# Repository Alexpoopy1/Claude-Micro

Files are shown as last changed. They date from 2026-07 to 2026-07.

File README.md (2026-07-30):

# Claude Micro

A 13-key agent macropad on clear MX switches: six frosted status keys, seven
command keys, a rotary reasoning dial, a planar joystick, a five-pad capacitive touch
strip and a 19-LED RGB chain. Fully printable, fully routed, fully checked.

Design study of the [Work Louder × OpenAI Codex Micro][codex] — same feature
set (13 switches, 1 encoder, 1 planar joystick, 1 touch sensor, 6 agent keys),
rebuilt from scratch as open hardware with the Claude mark on the front.

[codex]: https://openai.com/supply/co-lab/work-louder/

```
make            # build everything, then verify it
open build/claude-micro.html
```

Deploying to Vercel serves the same file: `vercel.json` runs the STL, PCB and
HTML build steps and publishes `build/` as the site, with `/` rewritten to
`claude-micro.html`. No framework, no Node build — just the Python tooling
above, so the deployed page is always generated fresh from
`config/device.json` rather than a stale checked-in copy.

## What you get

| Output | Where | What it is |
| --- | --- | --- |
| **Interactive viewer** | `build/claude-micro.html` | One self-contained file: WebGL model with an exploded-view slider, PCB layer viewer, schematic, BOM, print guide, firmware reference and the full check report. No network, no CDN. |
| **Printable parts** | `build/stl/*.stl` | 9 parts, 22 pieces, ~88 g of filament. Every one proven watertight before it is written. |
| **PCB** | `build/pcb/claude-micro.kicad_pcb` | Open in KiCad 7/8. Placed, routed, poured, zoned. Also `.kicad_sch`, `.kicad_pro`, `.net`. |
| **EasyEDA schematic** | `build/pcb/claude-micro-easyeda.json` | `make easyeda`. Opens in EasyEDA (File → Open → EasyEDA) and imports into EasyEDA Pro via File → Import → EasyEDA Standard — for publishing to OSHWLab or ordering through JLCPCB. |
| **Fabrication** | `build/pcb/gerbers/` | RS-274X gerbers for all nine layers plus separate plated and non-plated Excellon drill files. Upload as-is. |
| **Assembly** | `build/pcb/bom.csv`, `positions.csv` | 18 BOM lines, 89 components, pick-and-place positions. |
| **Firmware** | `firmware/qmk/claude_micro/` | Drop-in QMK keyboard folder. |
| **Reports** | `build/pcb/drc_report.json`, `build/stl_report.json` | Machine-readable results of every check. |

## Hardware

|  |  |
| --- | --- |
| Keys | 13 × clear-housing MX switches, 5-pin PCB mount, on a 19.05 mm grid — 6 agent, 7 command |
| Dial | EC11E rotary encoder with push, on a 26 mm knurled knob |
| Joystick | 20 mm 2-axis analog thumbstick into ADC0/ADC1, click on its own pin |
| Touch | 5-pad strip read by RC charge time — no touch controller |
| RGB | 19 × SK6812 (13 per-key + 6 underglow), 5 V through a 74LVC1G17 buffer |
| MCU | RP2040 module, Raspberry Pi Pico form factor (USB-C variant recommended) |
| Board | 159 × 102 mm, 2 layer, 1.6 mm, 0.2 mm rules |
| Case | 165 × 108 × 19.5 mm printed two-piece, 6° tilt feet |

### Agent keys

The six frosted keys mirror six host threads. The host pushes state over raw
HID and the board renders it:

| State | Colour | |
| --- | --- | --- |
| idle | white | nothing running |
| thinking | blue, breathing | model is reasoning |
| running | light blue, breathing | tools are executing |
| waiting | amber | needs your input |
| done | green | finished cleanly |
| error | red | failed |

If the host goes quiet for 30 s every key falls back to idle, so a crashed
bridge never leaves stale status on the desk.

### The dial

Turning it walks reasoning effort — low → medium → high → max. Pressing it is
an ordinary matrix key (row 3, col 1), so it can be remapped like any other.

## How it is built

Everything derives from **`config/device.json`**. Change the key pitch there
and the STLs, the board, the firmware descriptors and the viewer all move
together; the test suite fails if any of them disagree.

```
config/device.json      one source of truth
        │
tools/  device.py       loader + derived layout (LED chain, matrix nodes, pads)
        mesh.py         watertight mesh kernel (no CSG, no dependencies)
        parts.py        every physical part, printable and purchased
        circuit.py      schematic as data: components, footprints, nets
        router.py       grid maze router + copper pour generator
        build_pcb.py    place → route → pour → check
        outputs.py      KiCad, gerbers, Excellon, BOM, board.json
        checks.py       ERC + DRC + mechanical fit
        schematic.py    SVG schematic
        build_easyeda.py   schematic → EasyEDA Standard source
        build_stl.py    printable parts → binary STL
        build_html.py   the single-file viewer
        build_firmware.py  QMK descriptors
tests/  test_all.py     36 checks across geometry, layout, circuit and board
```

No third-party packages. Python 3.11 standard library only.

### The mesh kernel

There is no CSG. Every solid is built from operations that are watertight by
construction — polygon extrusion, lofting, and lathing — and the awkward case
(capping an outline riddled with holes) is handled by a trapezoidal scanline
decomposition that re-subdivides the side walls so caps and walls share exactly
the same vertices. `Mesh.validate()` then *proves* each part is a closed,
consistently oriented 2-manifold with positive volume, and `build_stl.py`
refuses to write a file that fails.

### The router

The board is rasterised onto a 0.2 mm grid where every piece of copper is
stamped along with its clearance halo, so "may net N occupy this cell?" is one
array lookup. Nets are then routed shortest-first with A* over that grid, with
a cost for changing layer and a separate keepout map that stops a via being
drilled too close to another hole. Leftover free space becomes the ground pour,
emitted as scanline runs. Any GND pad the pour cannot reach gets found by a
flood fill and routed in with a track — the same flood fill the DRC uses, so
the fixer and the checker cannot drift apart.

## Verification

`make test` runs 36 checks:

* **Geometry** — kernel invariants, analytic volume checks, a fuzz pass over
  random hole patterns, and every printable part proven watertight, manifold,
  correctly oriented, printer-sized and thick enough to print.
* **Layout** — key pitch, top-surface collisions, bezel window clearances, a
  monotonic Z stack, and that the encoder shaft does not bottom out in the knob.
* **Circuit** — ERC, one switch and one diode per matrix node, unique matrix
  addresses, an unbroken LED chain, no double-booked GPIO, the LED rail fused
  and level-shifted, the touch strip fully wired.
* **Board** — every connection routed, ≥ 0.2 mm copper clearance verified on a
  fresh raster of the finished geometry, annular rings, hole-to-hole spacing,
  all copper inside the profile, the ground pour reaching every GND pad, no
  courtyard overlaps, and nothing under the MCU module taller than its standoff.
* **Outputs** — balanced s-expressions in the KiCad files, well-formed gerbers
  and Excellon, drill counts matching the board, the BOM covering every
  component, the viewer free of external references, and the firmware agreeing
  with the config on pins, LED count, layers and layout size.
* **EasyEDA** — every shape string matching EasyEDA's documented field order,
  no duplicate ids, and the connectivity rebuilt out of the exported file the
  way EasyEDA reads it — pin dot → wire → net label — coming back identical to
  the source netlist, all 265 pads and 68 nets.

Current status: **0 DRC errors, 0 warnings, 141/141 connections routed, 9/9
meshes watertight.**

## Building one

1. **Print** at 0.2 mm, 3 walls, 25% infill. No supports on any part. Print the
   six agent keycaps in natural or clear filament — the roof is 1.0 mm so the
   status colour reads through. All 13 caps take a standard MX cross stem, so
   bought keycaps drop straight in if you would rather not print them.
2. **Order the PCB** — upload `build/pcb/gerbers/` as a zip. Nothing exotic:
   2 layer, 1.6 mm, 0.2 mm track and clearance.
3. **Populate** — bottom side first (diodes, 0603s, the SOT-23-5, then the
   RP2040 module on a 2.54 mm header), then the top: the 19 SK6812s, then the
   13 MX switches, the EC11 and the thumbstick. Seat every switch fully — the
   two locating posts must bottom out before you solder, or the plate will not
   sit flat.
4. **Flash** — `qmk compile -kb claude_micro -km default`, hold BOOTSEL, copy
   the UF2 across.
5. **Assemble** — six M2 heat-set inserts in the bezel, drop the diffuser into
   the touch window, six M2 × 6 mm screws from underneath.

Full step-by-step with per-part orientation is in the viewer's
**Print & assemble** tab.

## Licence

Hardware and firmware are open. The Claude mark is Anthropic's; it is used here
on a personal build, not a product for sale.

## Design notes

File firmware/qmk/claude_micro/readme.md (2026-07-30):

# Claude Micro (QMK)

Drop this folder into `qmk_firmware/keyboards/` and build:

    qmk compile -kb claude_micro -km default

Flash by holding BOOTSEL on the RP2040 module while plugging in USB, then
copying the resulting `.uf2` onto the `RPI-RP2` drive that appears.

| File | What it does |
| --- | --- |
| `keyboard.json` | Matrix pins, encoder, RGB layout, USB descriptors — generated from `config/device.json` |
| `config.h` | Joystick, touch-strip and RGB tuning |
| `matrix.c` | 4x4 COL2ROW scan plus the thumbstick click on its own pin |
| `claude_micro.c` | Agent status LEDs, RC touch strip, joystick-to-skill mapping |
| `keymaps/default/keymap.c` | Six layers, encoder map, host-bridge keycodes |

Everything here is regenerated by `make firmware`, and `make test` fails if the
firmware and `config/device.json` ever disagree about pins, LED count or layers.

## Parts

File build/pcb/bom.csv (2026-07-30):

Qty | Value | Footprint | MPN / Notes | References | Description | Group
22 | 100nF | C_0603 | - | C1 C10 C11 C12 C13 C14 C15 C16 C17 C18 C19 C2 C20 C24 C25 C3 C4 C5 C6 C7 C8 C9 | Encoder B debounce | input
14 | 1N4148W | D_SOD123 | 1N4148W SOD-123 | D1 D10 D11 D12 D13 D14 D2 D3 D4 D5 D6 D7 D8 D9 | Matrix diode for ENC_SW | matrix
13 | MX clear | MX_PCB | MX-compatible, clear housing, 5-pin | SW1 SW10 SW11 SW12 SW13 SW2 SW3 SW4 SW5 SW6 SW7 SW8 SW9 | Key K7 | matrix
13 | SK6812MINI-E | SK6812MINI | SK6812MINI-E | LED1 LED10 LED11 LED12 LED13 LED2 LED3 LED4 LED5 LED6 LED7 LED8 LED9 | Per-key status RGB | rgb
6 | SK6812-3535 | SK6812_3535 | SK6812-3535 | LED14 LED15 LED16 LED17 LED18 LED19 | Underglow RGB | rgb
5 | 1M | R_0603 | - | R5 R6 R7 R8 R9 | RC touch drive resistor, pad 4 | touch
2 | 10uF | C_0805 | - | C22 C23 | 3V3 bulk | power
2 | 10k | R_0603 | - | R1 R2 | Encoder B pull-up | input
2 | 1k | R_0603 | - | R3 R4 | Joystick Y RC filter | input
2 | 10nF | C_0603 | - | C26 C27 | Joystick Y filter cap | input
1 | RP2040 Pico-form-factor module | RP2040_Module_Pico | YD-RP2040 / RP2040-Plus / Raspberry Pi Pico | MOD1 | RP2040 + 2-16 MB flash + USB + 3V3 regulator | mcu
1 | 470R | R_0603 | - | R10 | Data line series damping | rgb
1 | 74LVC1G17 | SOT-23-5 | SN74LVC1G17DBVR | U2 | Schmitt buffer, 3V3 -> 5V for SK6812 data | power
1 | 1.1A PPTC | F_1206 | MF-MSMF110 | F1 | Resettable fuse on the 5 V rail | power
1 | 470uF 10V | C_1210_BULK | Low-ESR bulk | C21 | LED rail bulk capacitance | power
1 | EC11E + switch | EC11E | EC11E15244Ax (9 mm shaft) | ENC1 | Reasoning-effort dial | input
1 | 2-axis analog thumbstick | Joystick_20mm | 20 mm planar thumbstick, 10k pots | JS1 | Skill launcher | input
1 | Reset | SW_Push_6mm | - | SW_RST | Pulls RUN low | mcu

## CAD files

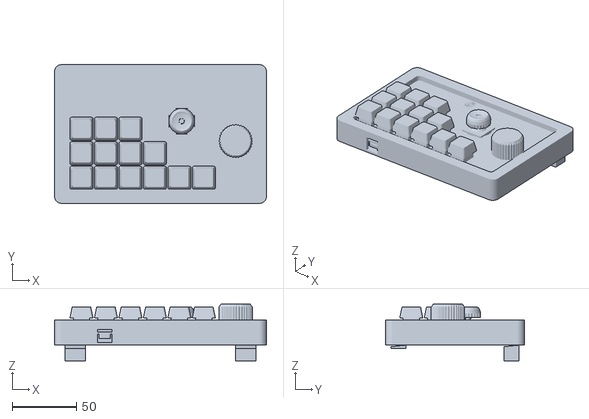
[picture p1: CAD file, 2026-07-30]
build/stl/assembly.stl
165.0 x 108.0 x 44.2

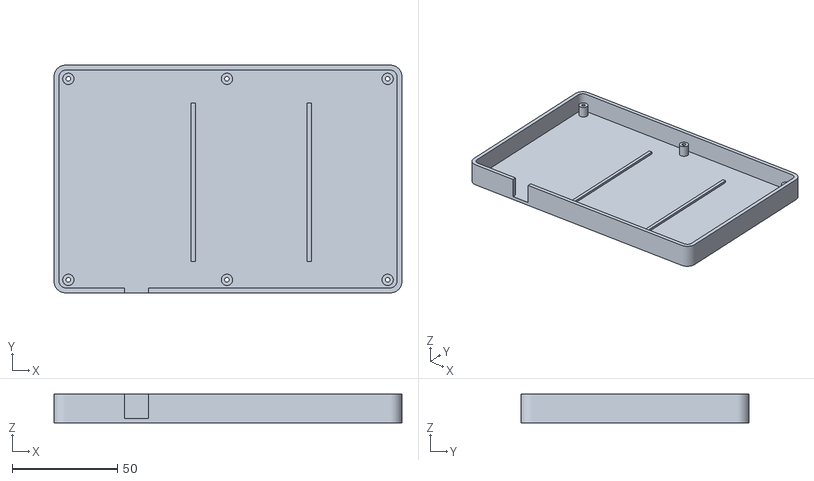
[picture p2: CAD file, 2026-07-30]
build/stl/case_bottom.stl
165.0 x 108.0 x 13.6

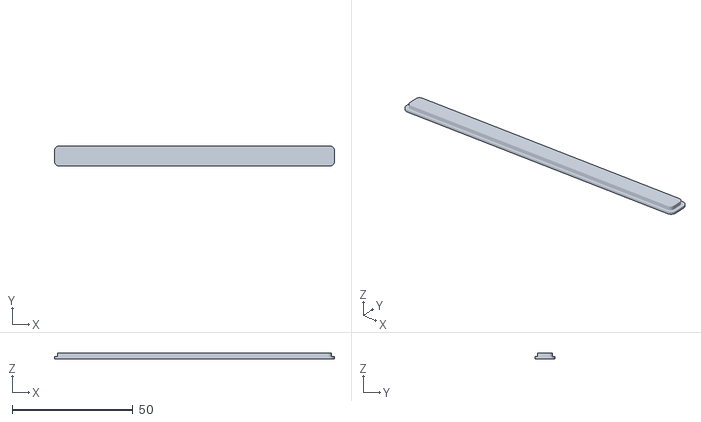
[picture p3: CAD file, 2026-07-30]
build/stl/diffuser.stl
115.8 x 8.40 x 2.30

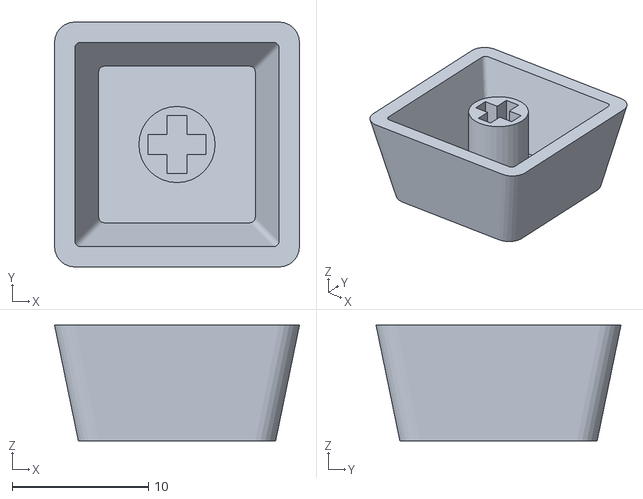
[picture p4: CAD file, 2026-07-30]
build/stl/keycap_agent.stl
18.0 x 18.0 x 8.50

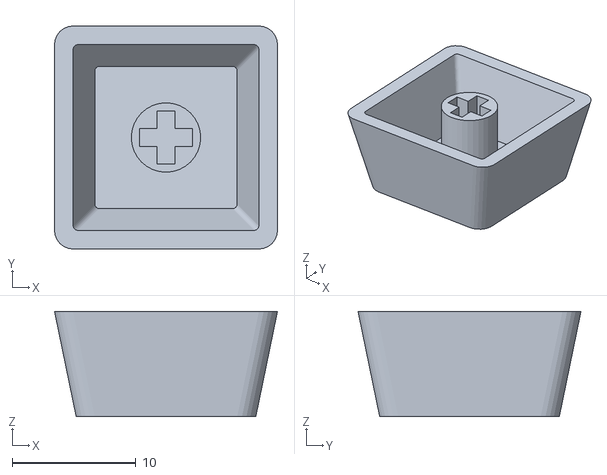
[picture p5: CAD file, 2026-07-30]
build/stl/keycap_command.stl
18.0 x 18.0 x 8.50

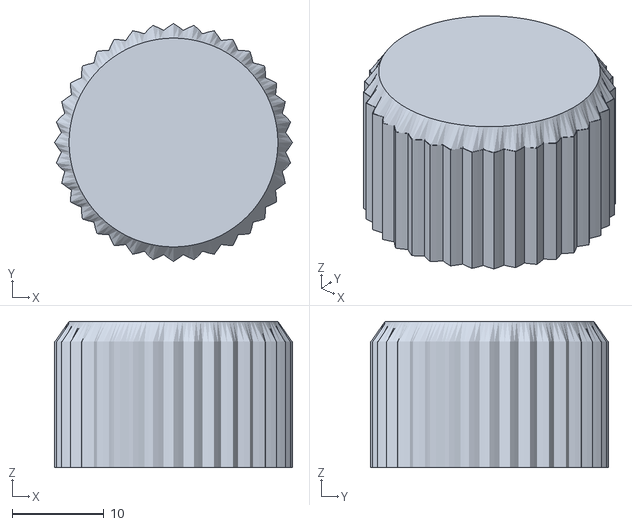
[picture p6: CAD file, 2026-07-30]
build/stl/knob.stl
26.0 x 26.0 x 16.0

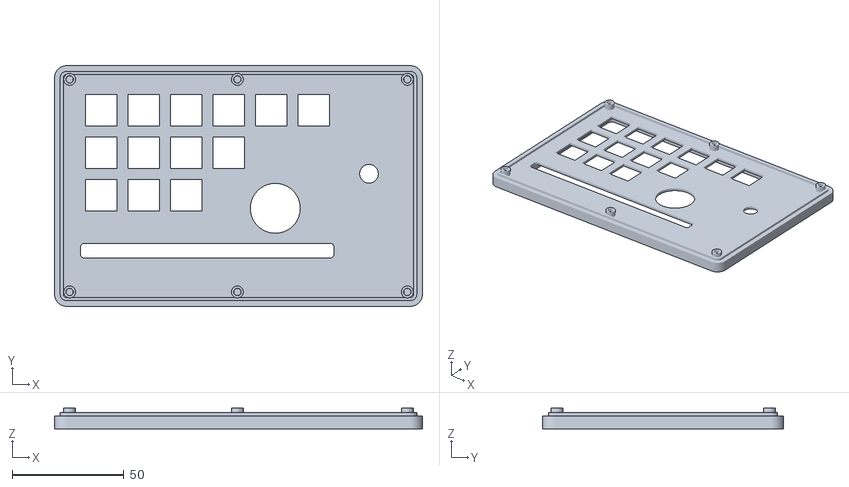
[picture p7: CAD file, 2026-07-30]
build/stl/case_top.stl
165.0 x 108.0 x 9.35

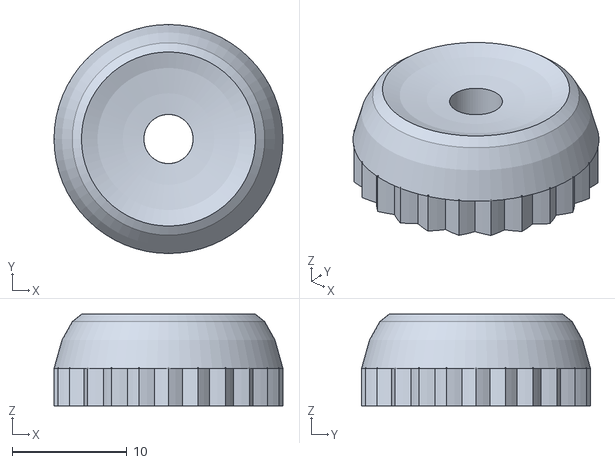
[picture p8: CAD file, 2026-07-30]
build/stl/joystick_cap.stl
20.0 x 20.0 x 8.00

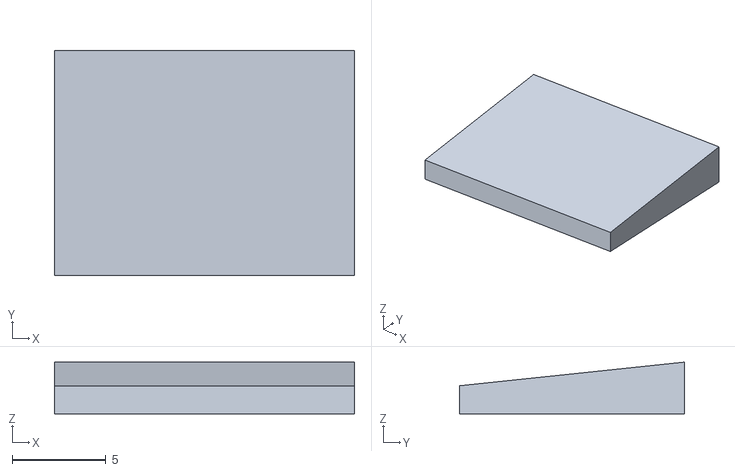
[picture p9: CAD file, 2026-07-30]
build/stl/foot_front.stl
16.0 x 12.0 x 2.76

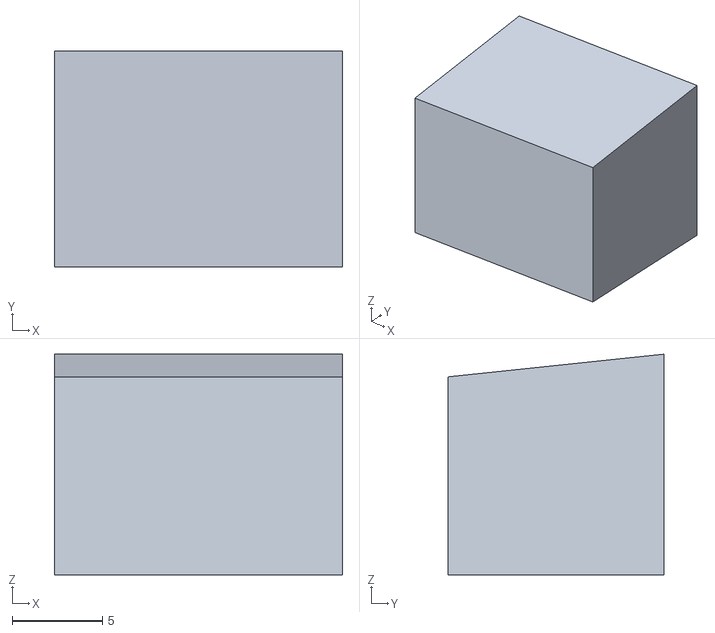
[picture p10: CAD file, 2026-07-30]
build/stl/foot_rear.stl
16.0 x 12.0 x 12.3

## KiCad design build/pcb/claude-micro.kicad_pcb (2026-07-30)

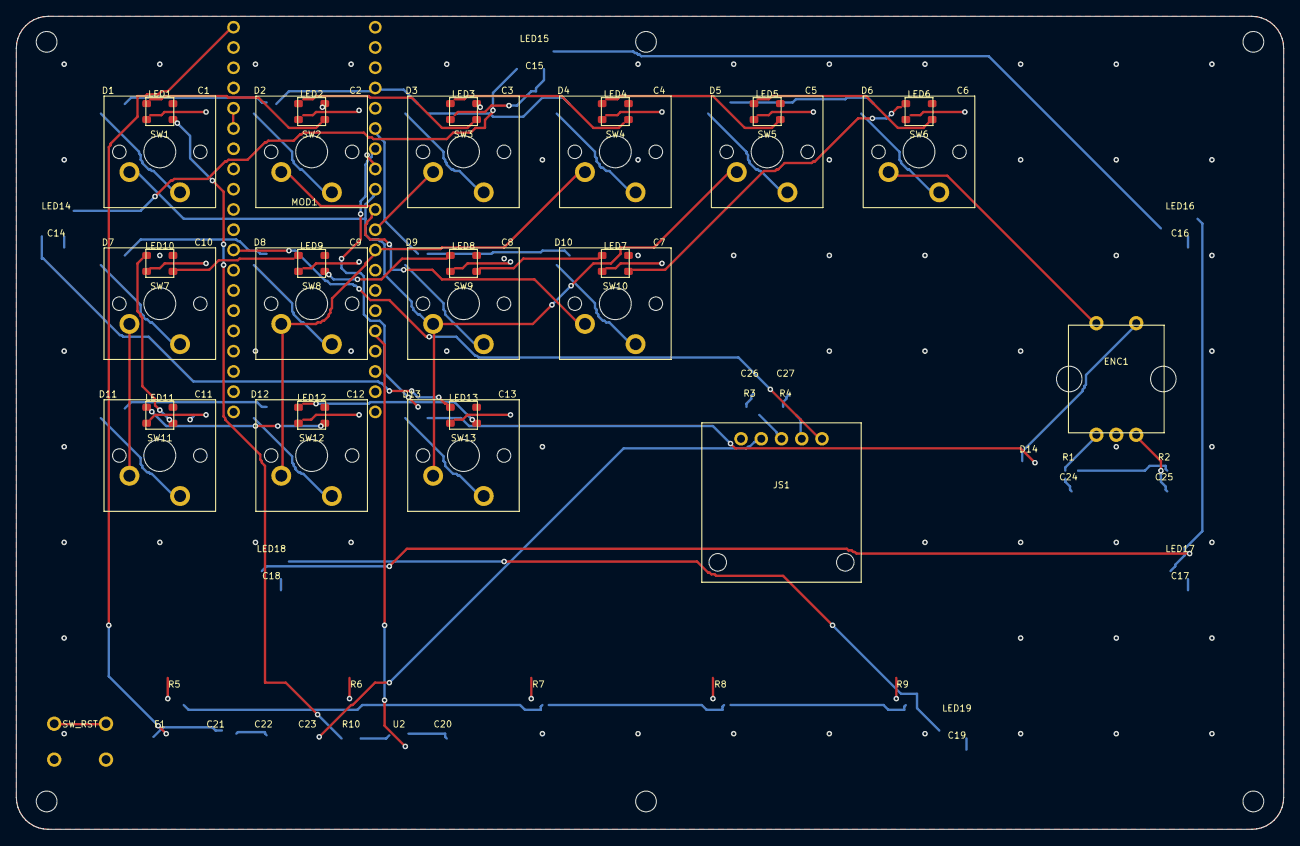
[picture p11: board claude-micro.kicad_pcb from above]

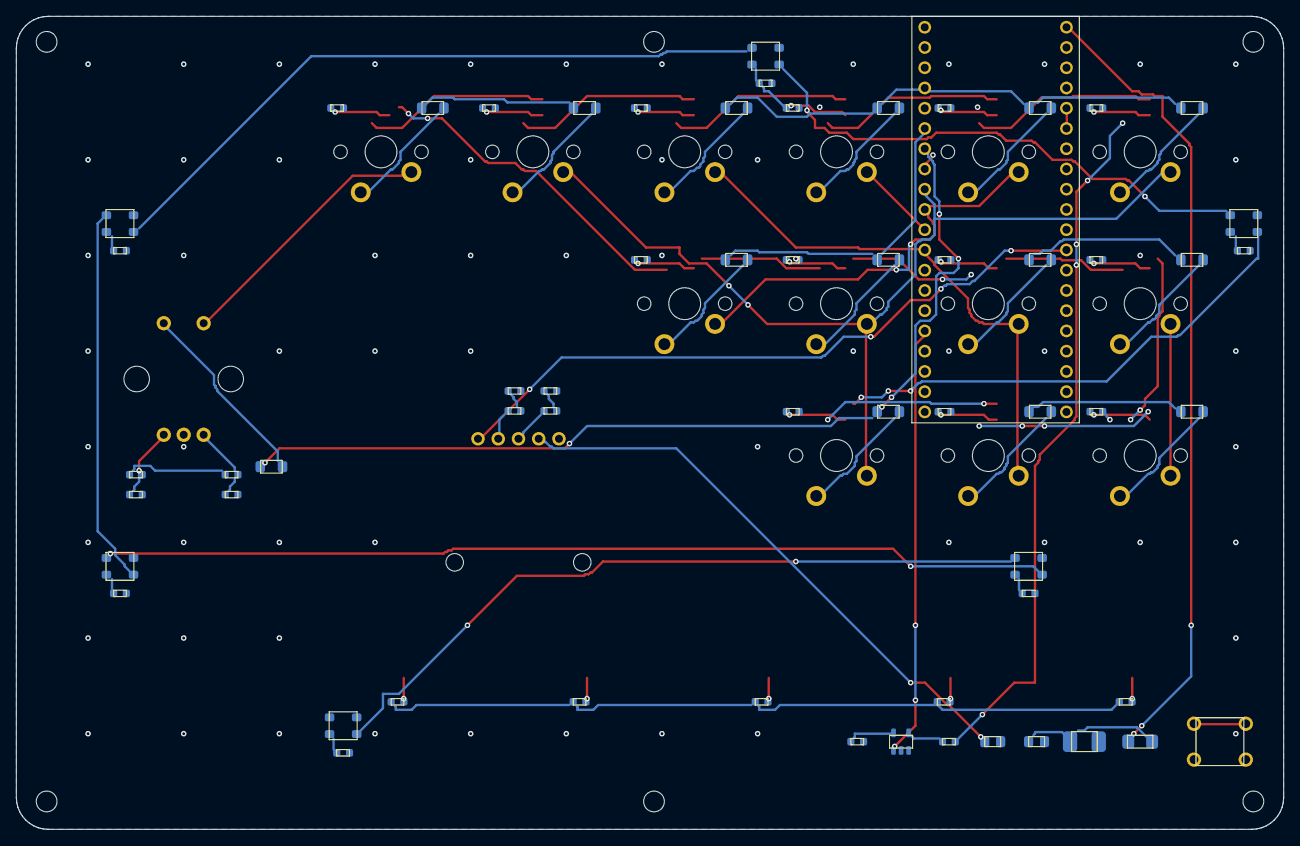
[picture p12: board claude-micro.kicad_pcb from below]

Board: 2 copper layers, 159.0 x 102.0 mm, 89 parts (61 on the bottom side), 61 nets.

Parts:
C1, C2, C3, C4, C5, C6, C7, C8, C9, C10, C11, C12, C13, C14, C15, C16, C17, C18, C19, C20, C24, C25: 100nF; C_0603
C21: 470uF 10V; C_1210_BULK
C22, C23: 10uF; C_0805
C26, C27: 10nF; C_0603
D1, D2, D3, D4, D5, D6, D7, D8, D9, D10, D11, D12, D13, D14: 1N4148W; D_SOD123
ENC1: EC11E + switch; EC11E
F1: 1.1A PPTC; F_1206
JS1: 2-axis analog thumbstick; Joystick_20mm
LED1, LED2, LED3, LED4, LED5, LED6, LED7, LED8, LED9, LED10, LED11, LED12, LED13: SK6812MINI-E; SK6812MINI
LED14, LED15, LED16, LED17, LED18, LED19: SK6812-3535; SK6812_3535
MOD1: RP2040 Pico-form-factor module; RP2040_Module_Pico
R1, R2: 10k; R_0603
R3, R4: 1k; R_0603
R5, R6, R7, R8, R9: 1M; R_0603
R10: 470R; R_0603
SW1, SW2, SW3, SW4, SW5, SW6, SW7, SW8, SW9, SW10, SW11, SW12, SW13: MX clear; MX_PCB
SW_RST: Reset; SW_Push_6mm
U2: 74LVC1G17; SOT-23-5

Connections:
+3V3: C23.1, JS1.2, MOD1.35, MOD1.36, R1.1, R2.1
+5V: C1.1, C2.1, C3.1, C4.1, C5.1, C6.1, C7.1, C8.1, C9.1, C10.1, C11.1, C12.1, C13.1, C14.1, C15.1, C16.1, C17.1, C18.1, C19.1, C20.1, C21.1, C22.1, F1.2, LED1.1, LED2.1, LED3.1, LED4.1, LED5.1, LED6.1, LED7.1, LED8.1, LED9.1, LED10.1, LED11.1, LED12.1, LED13.1, LED14.1, LED15.1, LED16.1, LED17.1, LED18.1, LED19.1, U2.5
COL0: MOD1.9, SW1.1, SW5.1, SW9.1, SW13.1
COL1: ENC1.S1, MOD1.10, SW2.1, SW6.1, SW10.1
COL2: MOD1.11, SW3.1, SW7.1, SW11.1
COL3: MOD1.12, SW4.1, SW8.1, SW12.1
ENC_A: C24.1, ENC1.A, MOD1.14, R1.2
ENC_B: C25.1, ENC1.B, MOD1.15, R2.2
GND: C1.2, C2.2, C3.2, C4.2, C5.2, C6.2, C7.2, C8.2, C9.2, C10.2, C11.2, C12.2, C13.2, C14.2, C15.2, C16.2, C17.2, C18.2, C19.2, C20.2, C21.2, C22.2, C23.2, C24.2, C25.2, C26.2, C27.2, ENC1.C, JS1.1, LED1.3, LED2.3, LED3.3, LED4.3, LED5.3, LED6.3, LED7.3, LED8.3, LED9.3, LED10.3, LED11.3, LED12.3, LED13.3, LED14.3, LED15.3, LED16.3, LED17.3, LED18.3, LED19.3, MOD1.3, MOD1.8, MOD1.13, MOD1.18, MOD1.23, MOD1.28, MOD1.33, MOD1.38, SW_RST.3, SW_RST.4, U2.2
JOY_SW: JS1.5, MOD1.29
JOY_X: C26.1, MOD1.31, R3.2
JOY_XR: JS1.3, R3.1
JOY_Y: C27.1, MOD1.32, R4.2
JOY_YR: JS1.4, R4.1
K_A1: D1.2, SW1.2
K_A2: D2.2, SW2.2
K_A3: D3.2, SW3.2
K_A4: D4.2, SW4.2
K_A5: D5.2, SW5.2
K_A6: D6.2, SW6.2
K_ENC_SW: D14.2, ENC1.S2
K_K1: D7.2, SW7.2
K_K2: D8.2, SW8.2
K_K3: D9.2, SW9.2
K_K4: D10.2, SW10.2
K_K5: D11.2, SW11.2
K_K6: D12.2, SW12.2
K_K7: D13.2, SW13.2
LED_D1: LED1.2, LED2.4
LED_D2: LED2.2, LED3.4
LED_D3: LED3.2, LED4.4
LED_D4: LED4.2, LED5.4
LED_D5: LED5.2, LED6.4
LED_D6: LED6.2, LED7.4
LED_D7: LED7.2, LED8.4
LED_D8: LED8.2, LED9.4
LED_D9: LED9.2, LED10.4
LED_D10: LED10.2, LED11.4
LED_D11: LED11.2, LED12.4
LED_D12: LED12.2, LED13.4
LED_D13: LED13.2, LED14.4
LED_D14: LED14.2, LED15.4
LED_D15: LED15.2, LED16.4
LED_D16: LED16.2, LED17.4
LED_D17: LED17.2, LED18.4
LED_D18: LED18.2, LED19.4
LED_DIN: LED1.4, R10.2
LED_DIN_3V3: MOD1.16, U2.1
LED_DIN_5V: R10.1, U2.4
RESET: MOD1.30, SW_RST.1, SW_RST.2
ROW0: D1.1, D2.1, D3.1, D4.1, MOD1.4
ROW1: D5.1, D6.1, D7.1, D8.1, MOD1.5
ROW2: D9.1, D10.1, D11.1, D12.1, MOD1.6
ROW3: D13.1, D14.1, MOD1.7
TOUCH0: MOD1.21, R5.2
TOUCH1: MOD1.22, R6.2
TOUCH2: MOD1.24, R7.2
TOUCH3: MOD1.25, R8.2
TOUCH4: MOD1.26, R9.2
TOUCH_DRV: MOD1.27, R5.1, R6.1, R7.1, R8.1, R9.1
VBUS: F1.1, MOD1.40

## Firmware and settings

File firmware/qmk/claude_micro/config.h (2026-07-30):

// Claude Micro - QMK configuration
// Drop this folder into qmk_firmware/keyboards/ and build with
//     qmk compile -kb claude_micro -km default

#pragma once

// ---------------------------------------------------------------- matrix
#define DEBOUNCE 5

// ------------------------------------------------------ joystick (ADC)
// Two 10k pots into ADC0/ADC1, each behind a 1k / 10nF filter.
#define JOY_X_PIN GP26
#define JOY_Y_PIN GP27
#define JOY_SW_PIN GP22
#define JOY_DEADZONE 380        // counts either side of centre, out of 2048
#define JOY_TRIGGER 900         // counts before a direction fires
#define JOY_REPEAT_MS 220

// ------------------------------------------------- capacitive touch strip
// GP21 drives all five pads through 1 MOhm; GP16..GP20 time the rising edge.
// No touch controller: the RC constant changes when a finger loads the pad.
#define TOUCH_PAD_COUNT 5
#define TOUCH_DRIVE_PIN GP21
#define TOUCH_SENSE_PINS { GP16, GP17, GP18, GP19, GP20 }
#define TOUCH_SAMPLES 8         // averaged per pad, per scan
#define TOUCH_THRESHOLD 22      // counts above the rolling baseline
#define TOUCH_BASELINE_SHIFT 9  // baseline tracks at 1/512 per scan
#define TOUCH_SWIPE_MS 320      // max time across the strip to count as a swipe

// ------------------------------------------------------------------- RGB
// 19 SK6812s: 13 per-key then 6 underglow. Full white on every channel would
// be ~1.1 A, so the effective brightness is capped to keep the whole board
// inside a 500 mA USB budget with headroom for the 1.1 A PPTC.
#define RGB_MATRIX_LED_COUNT 19
#define RGB_MATRIX_MAXIMUM_BRIGHTNESS 160
#define RGB_MATRIX_DEFAULT_MODE RGB_MATRIX_SOLID_COLOR
#define RGB_MATRIX_KEYPRESSES
#define WS2812_DI_PIN GP12
#define AGENT_LED_COUNT 6
#define AGENT_STATUS_TIMEOUT_MS 30000   // fall back to idle if the host goes quiet

// ------------------------------------------------------------------ misc
#define TAP_CODE_DELAY 8
#define ENCODER_RESOLUTION 4
#define DYNAMIC_KEYMAP_LAYER_COUNT 6
#define RAW_USAGE_PAGE 0xFF60
#define RAW_USAGE_ID 0x61

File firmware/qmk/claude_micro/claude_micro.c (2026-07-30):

// Claude Micro - board-level firmware.
//
// Three things live here that stock QMK does not provide:
//
//   1. agent status  - six frosted keys mirror the state of six host threads.
//                      The host pushes state over raw HID; the board renders it.
//   2. touch strip   - five pads read by RC charge time, turned into scroll
//                      ticks and taps.
//   3. joystick      - two ADC axes turned into four directional "skill" keys
//                      with a dead zone and auto-repeat.

#include QMK_KEYBOARD_H
#include "analog.h"
#include "raw_hid.h"
#include <string.h>

// ------------------------------------------------------------ agent status

typedef enum {
    AGENT_OFF = 0,
    AGENT_IDLE,
    AGENT_THINKING,
    AGENT_RUNNING,
    AGENT_WAITING,
    AGENT_DONE,
    AGENT_ERROR,
} agent_state_t;

static agent_state_t agent_state[AGENT_LED_COUNT] = {AGENT_IDLE};
static uint32_t      agent_last_update = 0;

// Matches config/device.json -> rgb.status_colors, so the physical board and
// the documentation cannot disagree.
static const uint8_t agent_rgb[][3] = {
    [AGENT_OFF]      = {  0,   0,   0},
    [AGENT_IDLE]     = {255, 255, 255},
    [AGENT_THINKING] = { 60, 120, 255},
    [AGENT_RUNNING]  = {120, 200, 255},
    [AGENT_WAITING]  = {255, 176,  32},
    [AGENT_DONE]     = { 40, 210, 120},
    [AGENT_ERROR]    = {235,  60,  60},
};

// Agent keys are LED indices 0..5 (chain order A1..A6).
static void render_agent_leds(uint8_t led_min, uint8_t led_max) {
    const uint32_t now  = timer_read32();
    const bool     stale = (now - agent_last_update) > AGENT_STATUS_TIMEOUT_MS;
    for (uint8_t i = 0; i < AGENT_LED_COUNT; i++) {
        if (i < led_min || i >= led_max) continue;
        agent_state_t s = stale ? AGENT_IDLE : agent_state[i];
        uint8_t r = agent_rgb[s][0], g = agent_rgb[s][1], b = agent_rgb[s][2];
        if (s == AGENT_THINKING || s == AGENT_RUNNING) {
            // Slow breathe so "working" reads differently from "settled".
            uint8_t phase = (uint8_t)((now / 4) + i * 24);
            uint16_t k    = 110 + (abs8(sin8(phase) - 128) >> 1);
            r = (uint8_t)((r * k) >> 8);
            g = (uint8_t)((g * k) >> 8);
            b = (uint8_t)((b * k) >> 8);
        }
        rgb_matrix_set_color(i, r, g, b);
    }
}

// Host protocol: [0]=0xA1, [1]=count, then one state byte per agent.
void raw_hid_receive(uint8_t *data, uint8_t length) {
    if (length < 2 || data[0] != 0xA1) return;
    uint8_t n = data[1] > AGENT_LED_COUNT ? AGENT_LED_COUNT : data[1];
    for (uint8_t i = 0; i < n && (uint8_t)(2 + i) < length; i++) {
        if (data[2 + i] <= AGENT_ERROR) agent_state[i] = (agent_state_t)data[2 + i];
    }
    agent_last_update = timer_read32();
}

// ------------------------------------------------------------ touch strip

static const pin_t touch_pins[TOUCH_PAD_COUNT] = TOUCH_SENSE_PINS;
static uint16_t    touch_baseline[TOUCH_PAD_COUNT];
static bool        touch_active[TOUCH_PAD_COUNT];
static int8_t      touch_first = -1;
static uint32_t    touch_started = 0;

// Charge the pad through the 1 MOhm resistor and count loops until it reads
// high. A finger adds capacitance, so the count rises.
static uint16_t touch_read(uint8_t i) {
    uint32_t total = 0;
    for (uint8_t s = 0; s < TOUCH_SAMPLES; s++) {
        gpio_set_pin_output(touch_pins[i]);
        gpio_write_pin_low(touch_pins[i]);
        wait_us(30);
        gpio_set_pin_input(touch_pins[i]);
        gpio_write_pin_high(TOUCH_DRIVE_PIN);
        uint16_t n = 0;
        while (!gpio_read_pin(touch_pins[i]) && n < 3000) n++;
        total += n;
        gpio_write_pin_low(TOUCH_DRIVE_PIN);
        wait_us(30);
    }
    return (uint16_t)(total / TOUCH_SAMPLES);
}

static void touch_init(void) {
    gpio_set_pin_output(TOUCH_DRIVE_PIN);
    gpio_write_pin_low(TOUCH_DRIVE_PIN);
    for (uint8_t i = 0; i < TOUCH_PAD_COUNT; i++) {
        gpio_set_pin_input(touch_pins[i]);
        touch_baseline[i] = touch_read(i);
    }
}

static void touch_task(void) {
    for (uint8_t i = 0; i < TOUCH_PAD_COUNT; i++) {
        uint16_t v    = touch_read(i);
        int32_t  diff = (int32_t)v - (int32_t)touch_baseline[i];
        bool     now  = diff > TOUCH_THRESHOLD;

        if (!now) {
            // Track slow drift (temperature, humidity) only while untouched.
            touch_baseline[i] += (int16_t)((diff) >> TOUCH_BASELINE_SHIFT);
        }
        if (now && !touch_active[i]) {
            if (touch_first < 0) {
                touch_first   = (int8_t)i;
                touch_started = timer_read32();
            } else if (timer_elapsed32(touch_started) < TOUCH_SWIPE_MS) {
                // Adjacent pad lit up in time: treat it as a swipe tick.
                if (i > (uint8_t)touch_first) tap_code(KC_WH_D);
                else if (i < (uint8_t)touch_first) tap_code(KC_WH_U);
                touch_first = (int8_t)i;
            }
        }
        if (!now && touch_active[i] && touch_first == (int8_t)i
            && timer_elapsed32(touch_started) < 180) {
            tap_code(KC_ESC);   // quick tap on a single pad = acknowledge
            touch_first = -1;
        }
        touch_active[i] = now;
    }
    if (touch_first >= 0 && timer_elapsed32(touch_started) > 900) touch_first = -1;
}

// -------------------------------------------------------------- joystick

enum joy_dir { JOY_NONE = 0, JOY_UP, JOY_DOWN, JOY_LEFT, JOY_RIGHT };

static uint16_t joy_centre_x = 2048, joy_centre_y = 2048;
static uint8_t  joy_last = JOY_NONE;
static uint32_t joy_next_repeat = 0;

static void joy_init(void) {
    // Calibrate the centre at power-up; the stick must be at rest.
    joy_centre_x = analogReadPin(JOY_X_PIN);
    joy_centre_y = analogReadPin(JOY_Y_PIN);
}

static uint8_t joy_direction(void) {
    int16_t dx = (int16_t)analogReadPin(JOY_X_PIN) - (int16_t)joy_centre_x;
    int16_t dy = (int16_t)analogReadPin(JOY_Y_PIN) - (int16_t)joy_centre_y;
    if (abs(dx) < JOY_DEADZONE && abs(dy) < JOY_DEADZONE) return JOY_NONE;
    if (abs(dx) > abs(dy)) {
        if (abs(dx) < JOY_TRIGGER) return JOY_NONE;
        return dx > 0 ? JOY_RIGHT : JOY_LEFT;
    }
    if (abs(dy) < JOY_TRIGGER) return JOY_NONE;
    return dy > 0 ? JOY_DOWN : JOY_UP;
}

// Each direction launches a Claude Code skill via a host-side shortcut.
static void joy_fire(uint8_t dir) {
    switch (dir) {
        case JOY_UP:    tap_code16(LCTL(LSFT(KC_R))); break;  // review PR
        case JOY_DOWN:  tap_code16(LCTL(LSFT(KC_D))); break;  // debug error
        case JOY_LEFT:  tap_code16(LCTL(LSFT(KC_F))); break;  // refactor
        case JOY_RIGHT: tap_code16(LCTL(LSFT(KC_T))); break;  // run tests
        default: break;
    }
}
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

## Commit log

2026-07-30 Claude Micro: printable 13-key agent macropad, fully routed and verified
    A complete open-hardware build generated from one config file: printable
    case and caps, a placed-and-routed two-layer PCB with fabrication outputs,
    QMK firmware, and a self-contained interactive viewer.
    Design study of the Work Louder x OpenAI Codex Micro - same feature set
    (13 switches, rotary encoder, planar joystick, capacitive touch sensor,
    6 frosted agent keys) rebuilt from scratch with the Claude mark.
    Everything derives from config/device.json, so the geometry, the board, the
    firmware descriptors and the viewer cannot disagree; tests/test_all.py fails
    if they do.
    Geometry
    - Dependency-free watertight mesh kern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
    [B_Cu.gbr, B_Mask.gbr, B_Paste.gbr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]
2026-07-30 Add Vercel config to deploy the interactive viewer as a website
    vercel.json runs the STL, PCB and HTML build steps and publishes build/ as
    the site, with / rewritten to claude-micro.html. No framework, no Node
    build - just the existing Python tooling, so the deployed page is always
    generated fresh from config/device.json instead of serving a stale
    checked-in copy. STL, gerber, drill and KiCad files under build/ get a
    Content-Disposition: attachment header so they download instead of
    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
2026-07-30 Add EasyEDA schematic export
    New `make easyeda` target writes build/pcb/claude-micro-easyeda.json from the
    same netlist that drives the PCB and the KiCad output. It opens in EasyEDA
    (File -> Open -> EasyEDA) and imports into EasyEDA Pro via File -> Import ->
    EasyEDA Standard, which is the path to OSHWLab and to ordering through JLCPCB.
    Field orders for every shape string (LIB, R, T, P, W, N) were taken from
    EasyEDA's published document format and checked against a real exported
    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
2026-07-30 Switch to clear MX switches; fix the EasyEDA project wrapper
    Two changes.
    EasyEDA
    -------
    The project wrapper now matches what EasyEDA 6.5 actually writes: docType is
    the string "5" (not the integer 5), colors is an object, editorVersion sits at
    the top level alongside a description, and each sheet carries its own string
    docType and description. The 4.x shape I had reverse-engineered from an older
    exported file would not round-trip. The structural test now asserts the exact
    key set and types on both the project and the sheet.
    Switches
    --------
    Kailh Choc low-profile replaced with clear-housing MX-compatible switches,
    5-pin PCB mount. That is not a drop-in: MX needs a 19.05 mm grid where Ch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
    [B_Cu.gbr, B_Mask.gbr, B_Paste.gbr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]
